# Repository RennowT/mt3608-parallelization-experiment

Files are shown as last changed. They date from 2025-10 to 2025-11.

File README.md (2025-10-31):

# MT3608 Paralelization Experiment

## Overview
This project aims to **develop and validate** a DC-DC boost module composed of **three MT3608 converters in parallel**, designed to **step up voltage to 5 V** with a **target output current of up to 6 A**.

The goal is to evaluate whether multiple MT3608 converters can operate reliably in parallel while maintaining voltage stability, current sharing, and thermal safety.

---

## Objectives
- Design a parallel configuration using **three MT3608 step-up converters**.
- Achieve an **output voltage of 5 V** and up to **6 A total output current**.
- Evaluate **load balancing** and **thermal performance** between converters.
- Analyze the **limitations and failure modes** of MT3608 parallelization.

---

## Current Status
> The project is in an experimental stage.  
> There is **no current validation** that the configuration can achieve the specified current or stability requirements.

Prototype testing and measurement phases are ongoing. Future updates will include:
- Schematics and PCB layout
- Test data (efficiency, ripple, current sharing)
- Thermal analysis

---

## Technical Information
- **IC:** MT3608 (AEROSEMI)
- **Input voltage:** 2 V – 5 V
- **Target output:** 5 V / 6 A (shared)
- **Switching frequency:** 1.2 MHz
- **Topology:** Parallel step-up (boost) converters
- **Package:** SOT-23-6L

---

## License
This project is licensed under the  
**Creative Commons Attribution-NonCommercial-ShareAlike 4.0 International (CC BY-NC-SA 4.0)**.

See the [LICENSE](./LICENSE) file for details.

---

## Author
**Matheus Renó Torres**  
Hardware Research & Development  
2025

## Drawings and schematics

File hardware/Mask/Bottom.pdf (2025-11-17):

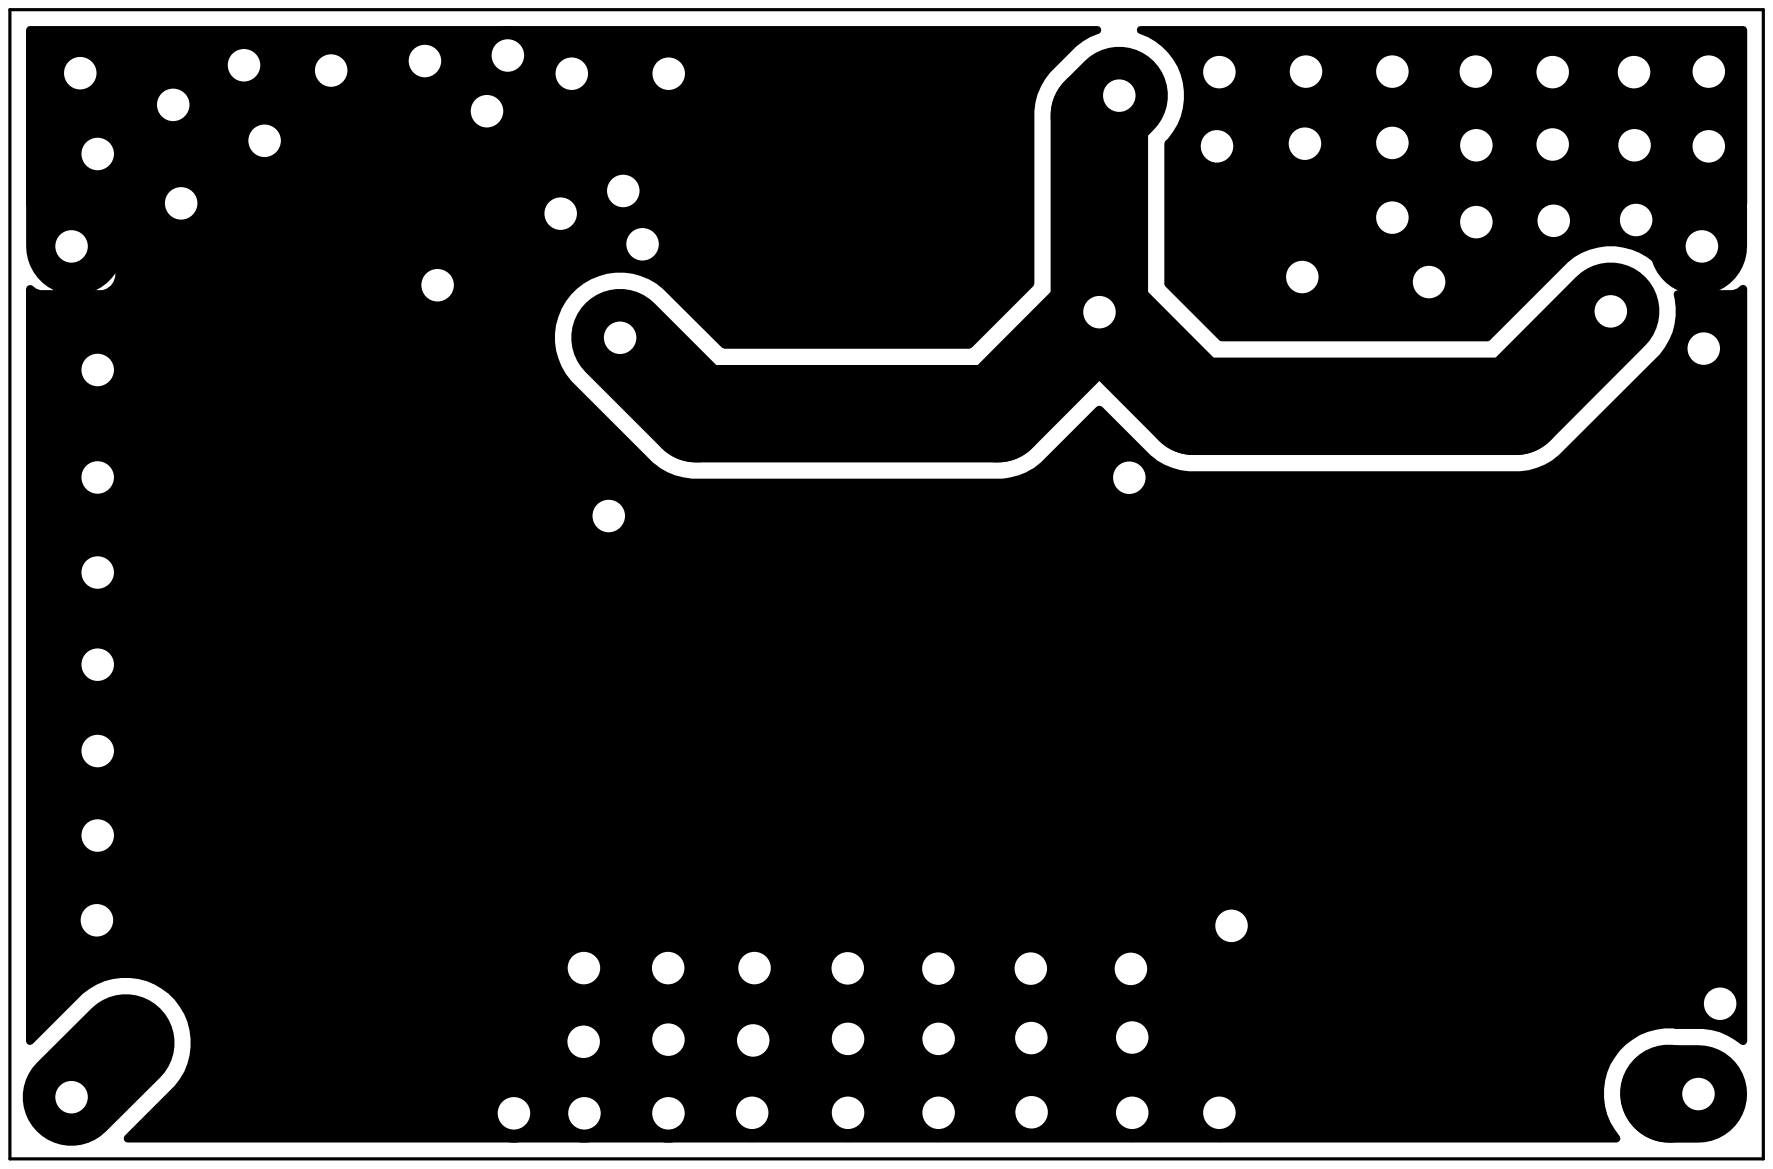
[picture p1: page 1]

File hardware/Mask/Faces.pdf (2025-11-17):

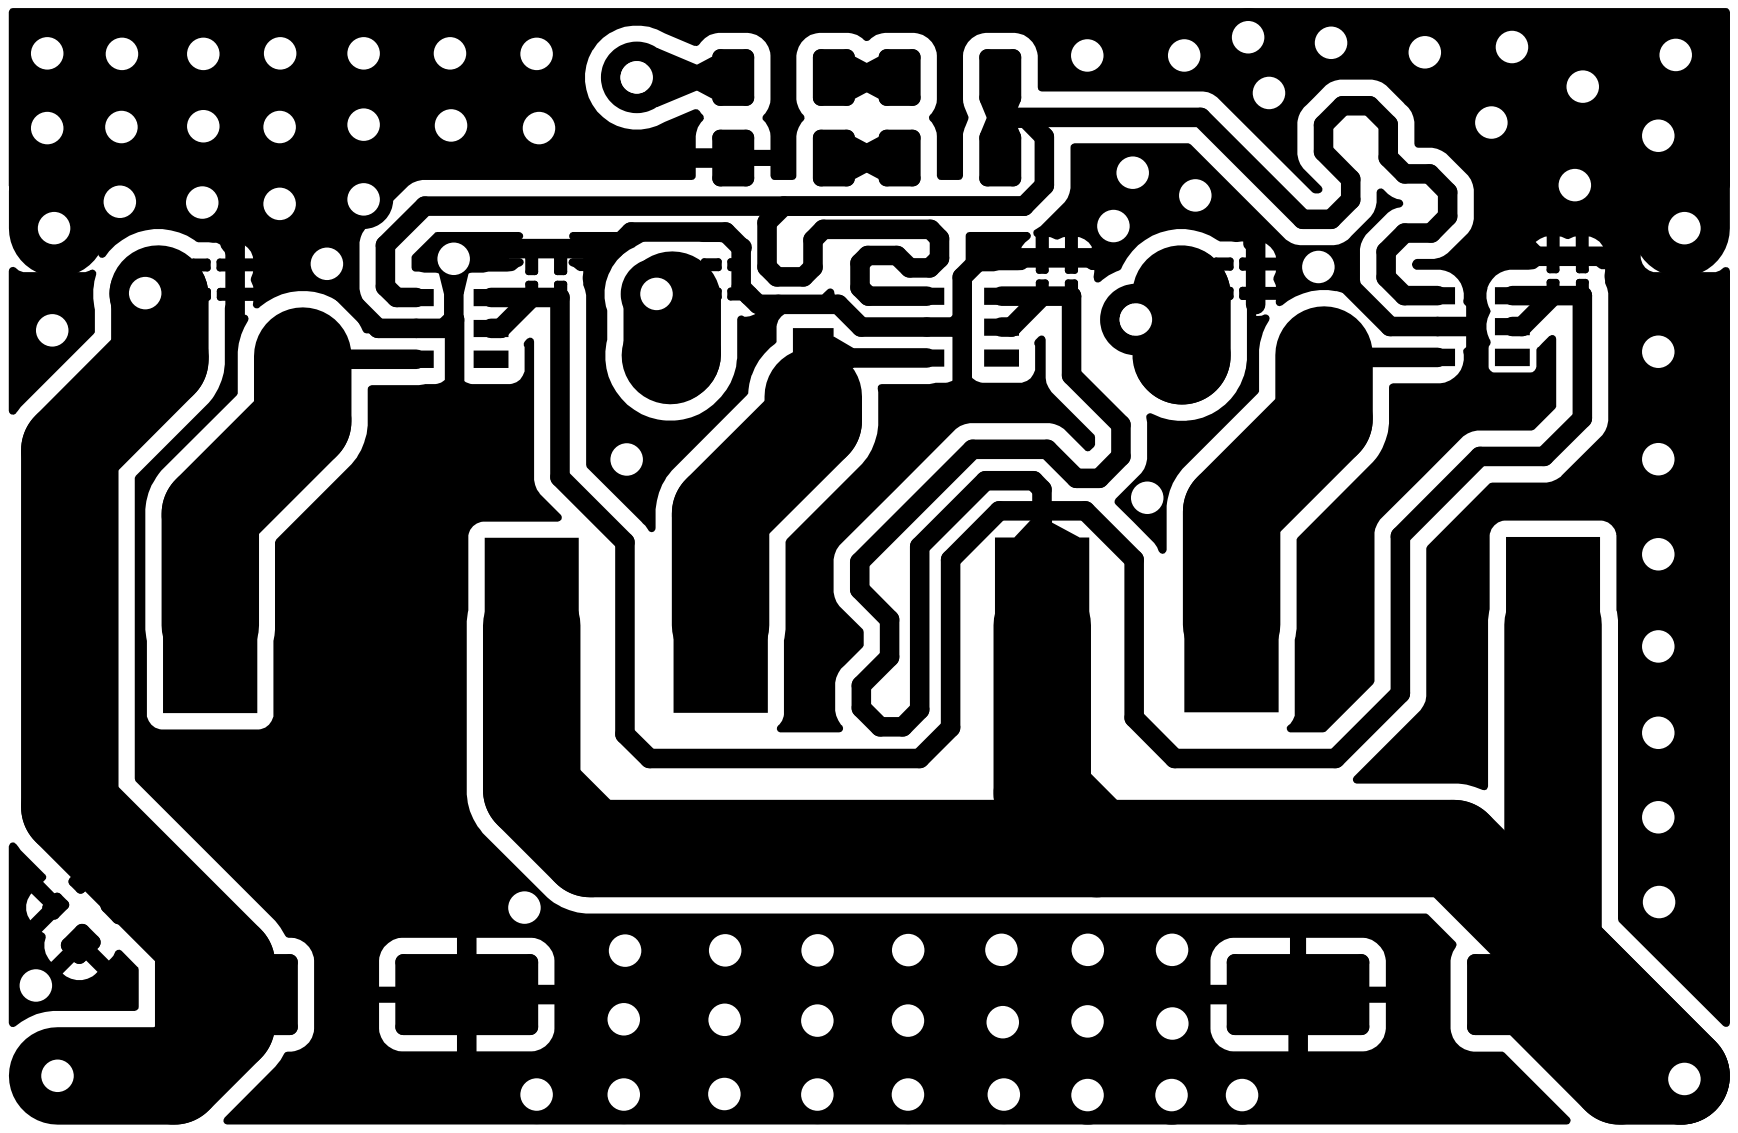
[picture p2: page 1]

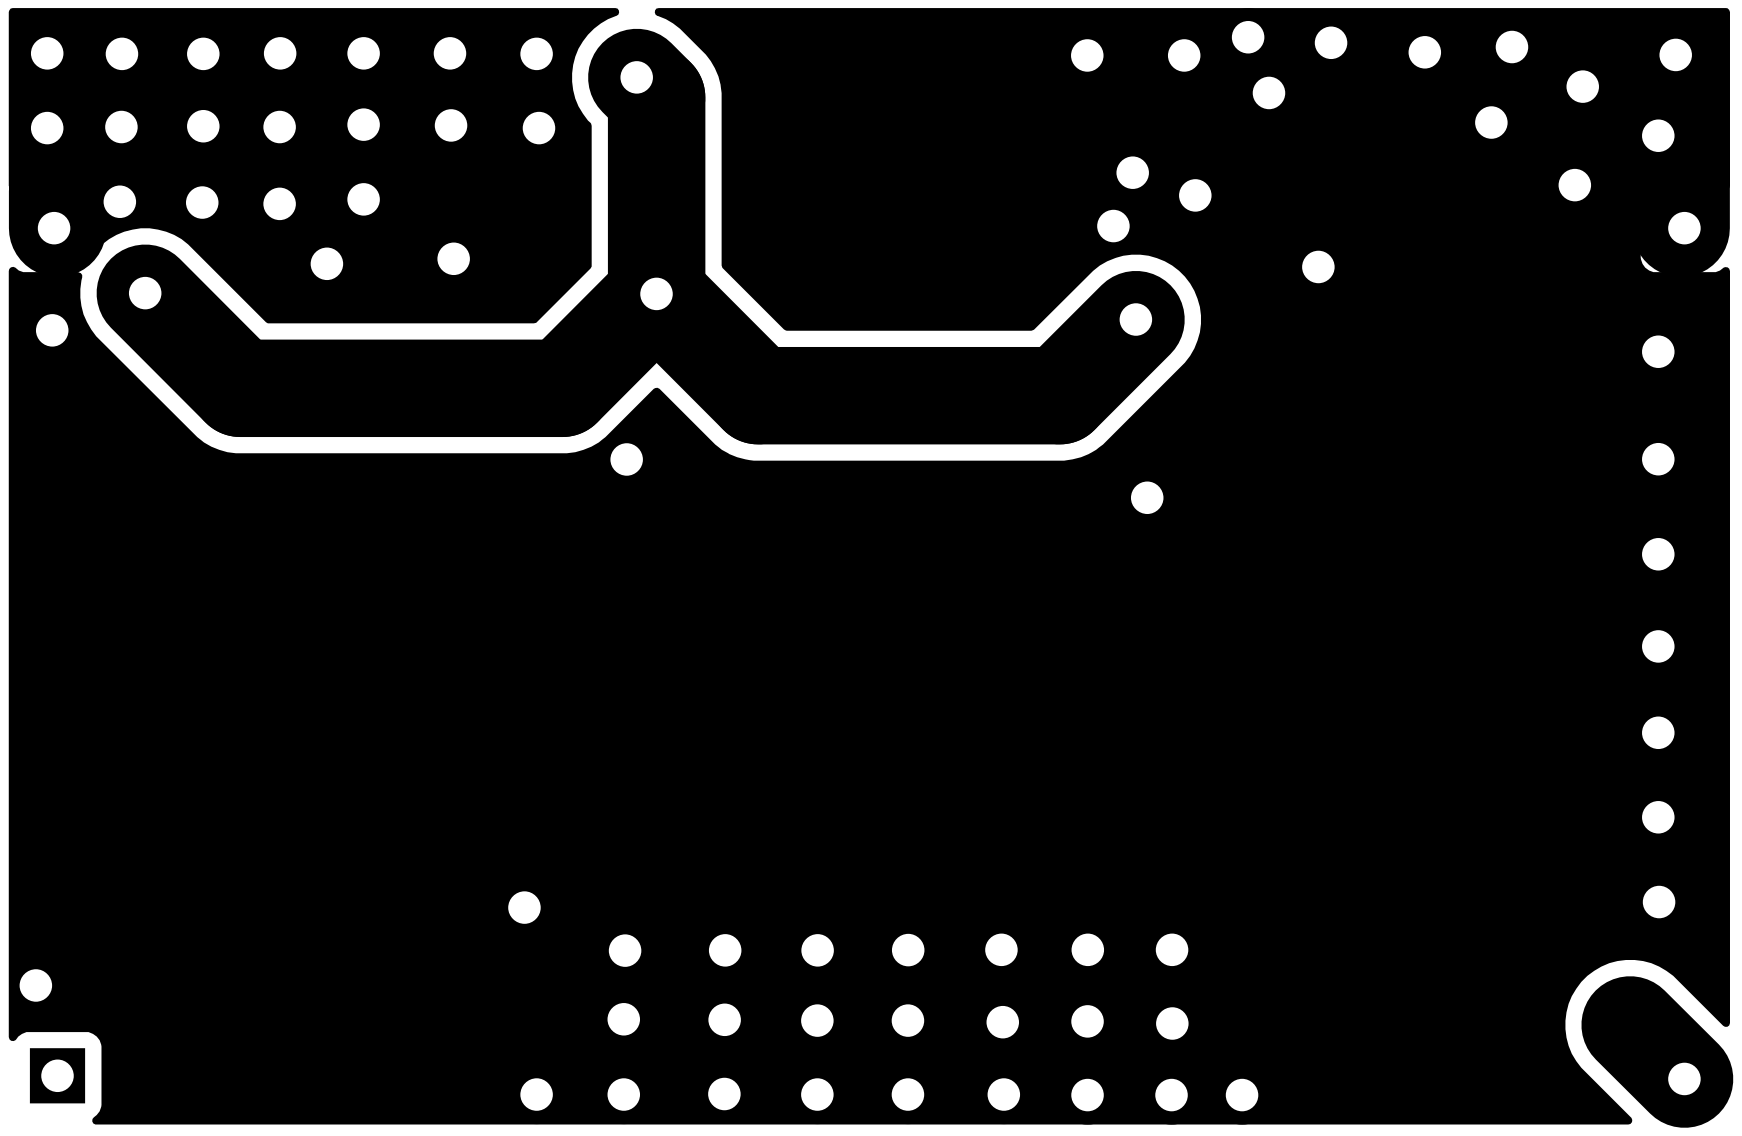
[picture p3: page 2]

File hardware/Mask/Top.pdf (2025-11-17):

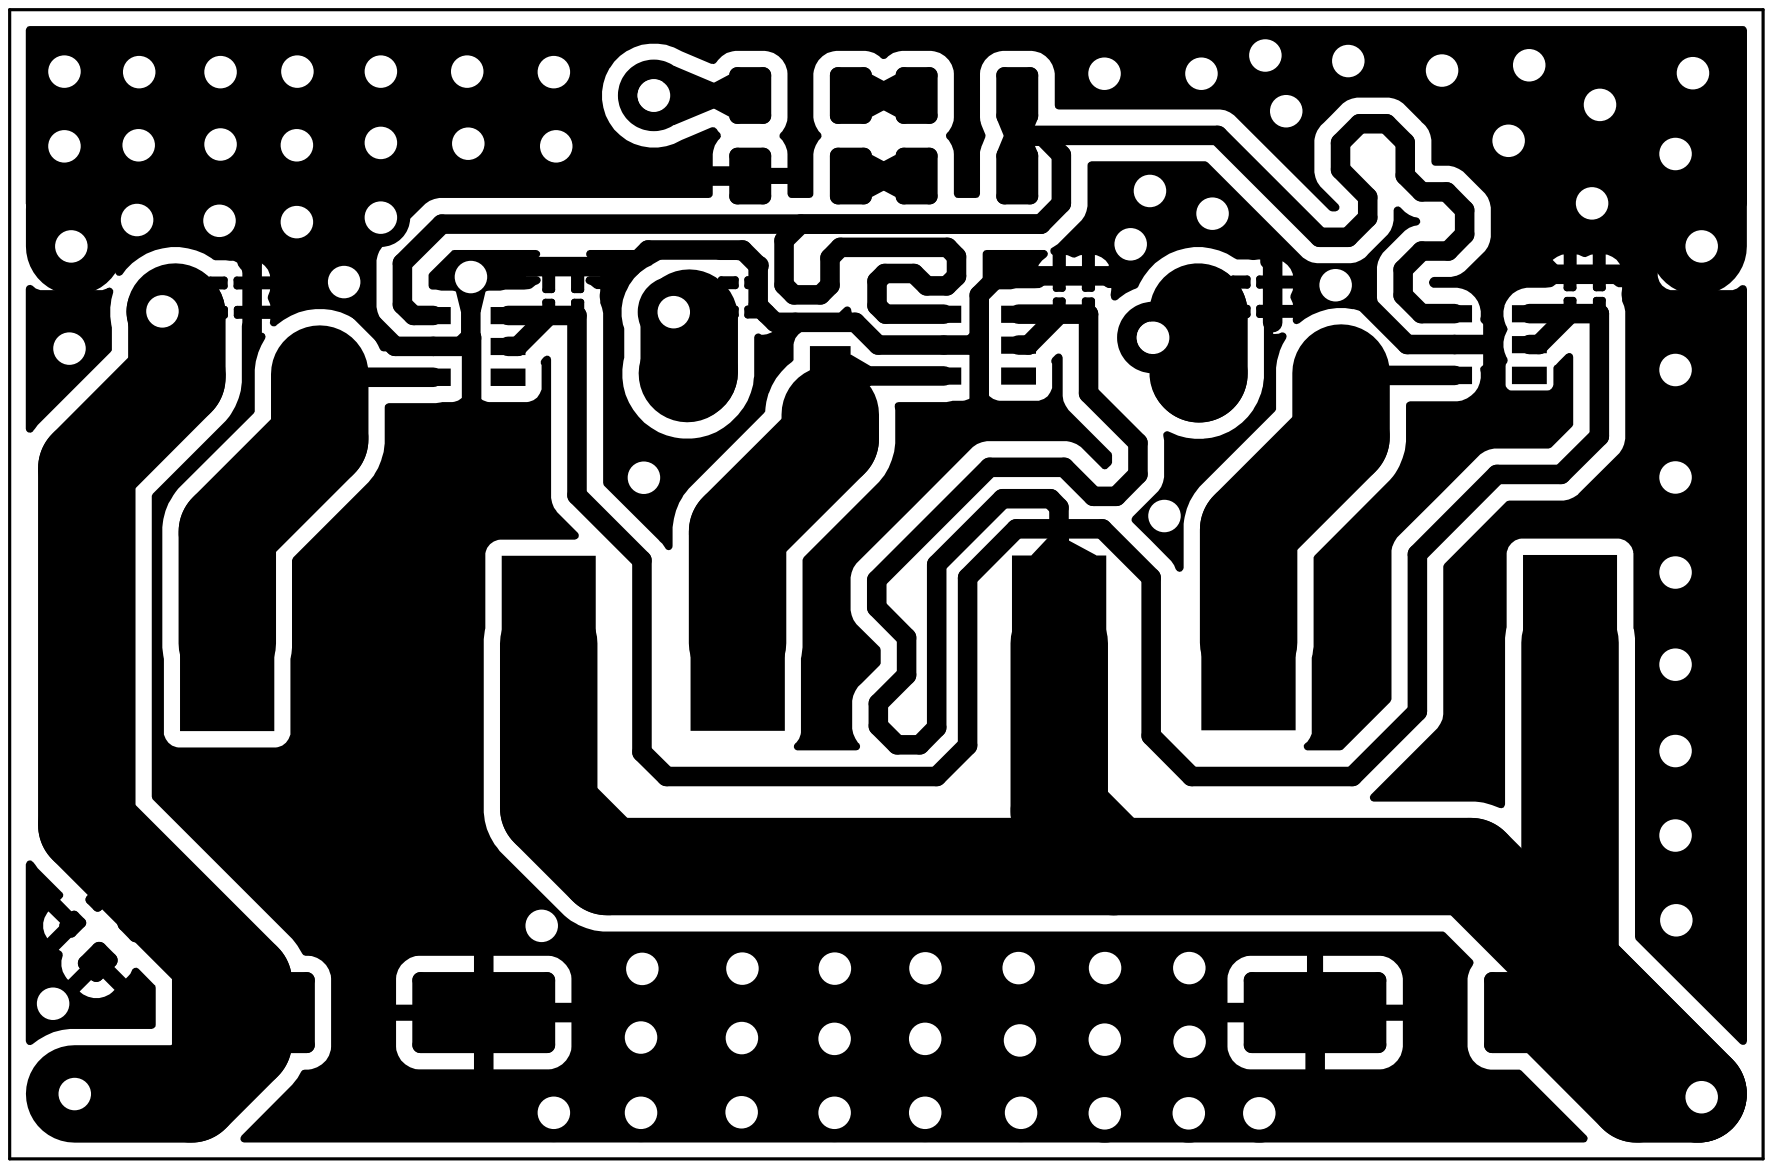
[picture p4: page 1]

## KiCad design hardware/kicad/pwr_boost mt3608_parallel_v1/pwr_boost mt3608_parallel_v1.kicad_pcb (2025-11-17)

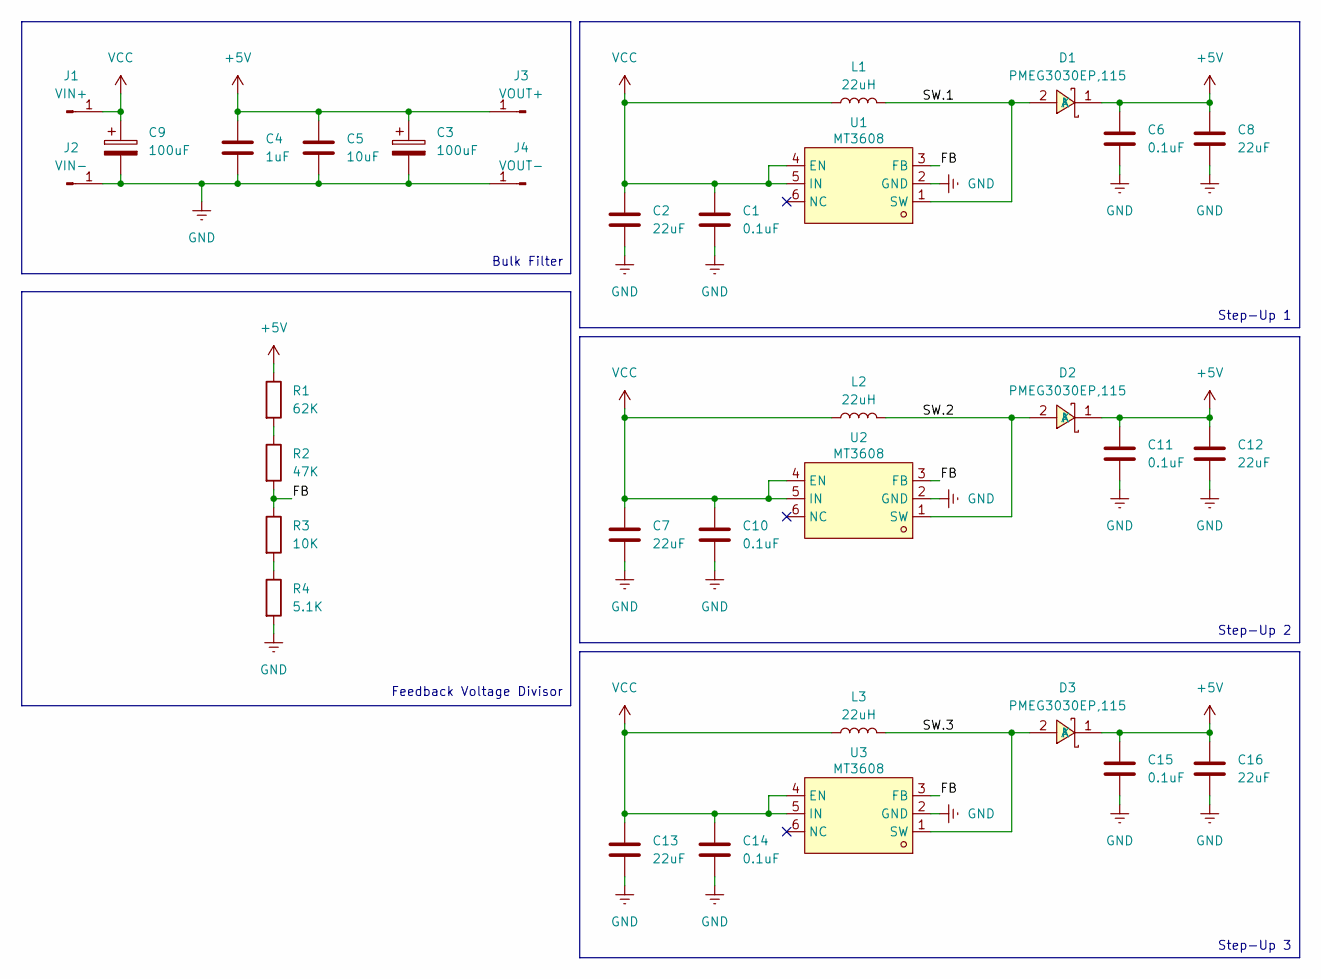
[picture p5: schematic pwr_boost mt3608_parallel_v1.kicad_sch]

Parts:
C1, C6, C10, C11, C14, C15: 0.1uF; C_0201_0603Metric_Pad0.64x0.40mm_HandSolder
C2, C7, C8, C12, C13, C16: 22uF; C_0201_0603Metric_Pad0.64x0.40mm_HandSolder
C3, C9: 100uF; CP_Elec_8x10.5
C4: 1uF; C_0402_1005Metric_Pad0.74x0.62mm_HandSolder
C5: 10uF; C_0603_1608Metric_Pad1.08x0.95mm_HandSolder
D1, D2, D3: PMEG3030EP,115; SOD-128_L3.7-W2.5-LS4.7-RD; LCSC Part C255587
J1: VIN+
J2: VIN-
J3: VOUT+
J4: VOUT-
L1, L2, L3: 22uH; L_12x12mm_H8mm
R1: 62K; R_1206_3216Metric_Pad1.30x1.75mm_HandSolder
R2: 47K; R_1206_3216Metric_Pad1.30x1.75mm_HandSolder
R3: 10K; R_1206_3216Metric_Pad1.30x1.75mm_HandSolder
R4: 5.1K; R_1206_3216Metric_Pad1.30x1.75mm_HandSolder
U1, U2, U3: MT3608; SOT-23-6_L2.9-W1.6-P0.95-LS2.8-BL; LCSC Part C84817

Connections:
+5V: C3.1, C4.1, C5.1, C6.1, C8.1, C11.1, C12.1, C15.1, C16.1, D1.1 (K), D2.1 (K), D3.1 (K), J3.1, R1.1
/FB: R2.2, R3.1, U1.3 (FB), U2.3 (FB), U3.3 (FB)
/SW.1: D1.2 (A), L1.2, U1.1 (SW)
/SW.2: D2.2 (A), L2.2, U2.1 (SW)
/SW.3: D3.2 (A), L3.2, U3.1 (SW)
GND: C1.2, C2.2, C3.2, C4.2, C5.2, C6.2, C7.2, C8.2, C9.2, C10.2, C11.2, C12.2, C13.2, C14.2, C15.2, C16.2, J2.1, J4.1, R4.2, U1.2 (GND), U2.2 (GND), U3.2 (GND)
unnamed: R1.2, R2.1
unnamed: R3.2, R4.1
VCC: C1.1, C2.1, C7.1, C9.1, C10.1, C13.1, C14.1, J1.1, L1.1, L2.1, L3.1, U1.4 (EN), U1.5 (IN), U2.4 (EN), U2.5 (IN), U3.4 (EN), U3.5 (IN)

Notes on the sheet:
Step-Up 3
Bulk Filter
Step-Up 2
Feedback Voltage Divisor
Step-Up 1

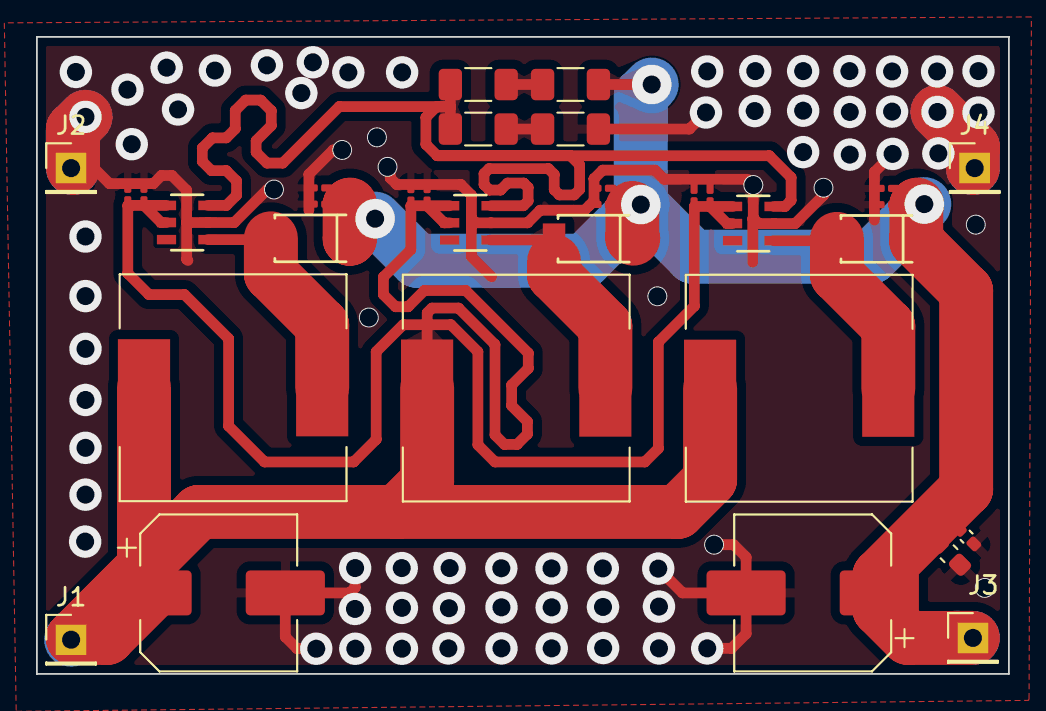
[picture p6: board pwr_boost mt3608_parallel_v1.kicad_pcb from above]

Board: 2 copper layers, 54.0 x 35.4 mm, 33 parts (0 on the bottom side), 9 nets.

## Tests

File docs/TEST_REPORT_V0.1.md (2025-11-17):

# **Version 0.1 — Test Report and Analysis**

## **1. Objective**

Evaluate the behavior of the parallel MT3608 boost converter architecture in an unloaded condition and identify whether all regulators operate simultaneously or if one device dominates the regulation loop.

---

## **2. Test Setup**

* **Input voltage:** 3.7 V
* **Output load:** No load (open circuit)
* **Expected output:** ~5 V
* **Measurement tools:**

  * Oscilloscope (probe on SW pin of each MT3608)
* **Configuration:**

  * Three MT3608 units connected in parallel
  * Shared FB node and identical resistor network
  * Shared output capacitor bank

---

## **3. Test Procedures and Observations**

### **3.1 Initial Power-Up**

* A voltage of **3.7 V** was applied to the input of the system.
* With no load, the output voltage measured **4.92 V**.

### **3.2 Oscilloscope Analysis (SW Pin)**

* The oscilloscope probe was placed on the **SW pin of each MT3608**.
* **Only one IC** showed the normal switching waveform expected from a functioning MT3608.
* The other two devices remained inactive (standby), indicating that only a **single MT3608 was regulating the output**, while the others were not contributing.

### **3.3 Feedback Trace Verification**

* The MT3608 ICs were swapped in their positions to verify whether a PCB feedback-trace issue was preventing regulation.
* After swapping, **the same IC continued to regulate**, regardless of its physical position.
* This eliminates the possibility of a feedback routing or soldering issue on the PCB.

### **3.4 Removal of the Regulating IC**

* The functioning IC was removed from the circuit to observe the behavior of the remaining two devices.
* After removal:

  * A different MT3608 began regulating normally.
  * The third MT3608 continued in standby, unchanged.
  * The new output voltage became **4.83 V**.

---

## **4. Interpretation**

The behavior strongly suggests **mismatch in the internal feedback reference (FB offset)** between individual MT3608 units.
Even within the same manufacturing lot, boost converters can have small variations in the internal 0.6 V reference used for regulation.

Because of this:

* The MT3608 that naturally regulates to the **highest output voltage** becomes the dominant controller.
* It maintains VOUT on its own.
* The other ICs detect that the output voltage is already above their regulation threshold and therefore enter a **standby / PFM state**, never turning on.
* This prevents proper current sharing and makes true parallel operation impossible under the current architecture.

---

## **5. Conclusion**

* The prototype assumed that all MT3608 devices would have identical regulation points; however, real-world variations in **feedback reference voltage** cause each IC to regulate at slightly different output voltages.
* **Only the MT3608 with the highest internal reference (highest regulated VOUT)** becomes active, while the others remain idle.
* This confirms that the current parallel architecture is **not viable** for ensuring simultaneous operation of multiple MT3608 regulators.
* A new design approach is required — one that:

  * Does **not** rely on identical reference voltages,
  * Provides **true current sharing**,
  * Or uses a **single master regulator** followed by distribution elements.

---

## **6. Recommended Next Steps**

To enable proper **parallel operation of multiple MT3608 regulators**, the design must account for the natural variation in the internal 0.6 V feedback reference of each device. Since each MT3608 regulates to a slightly different voltage, only the unit with the highest reference becomes active while the others remain in standby.
A new approach must ensure that all regulators can share current simultaneously.

Recommended next steps:

* Implement a **current-sharing method** between the MT3608 outputs to prevent one IC from dominating the regulation loop.
* Add small **ballast resistors** on each MT3608 output to equalize voltage differences and encourage parallel contribution.
* Isolate each feedback network in a way that minimizes interaction while still maintaining a common output target.
* Evaluate the effect of slightly adjusting the resistor divider of each MT3608 to compensate for reference mismatch.
* Test dynamic behavior under load to understand how the converters transition between PWM and PFM modes when operating together.
* Characterize the feedback reference variation of each MT3608 to define equalization strategies.

This approach retains the goal of **making the MT3608 chips operate in parallel**, avoiding standby dominance and ensuring stable current sharing.

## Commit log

2025-10-31 Revise README with project details and structure
    Updated project title and added detailed sections on objectives, current status, technical information, license, and author.
2025-11-17 feat: hardware design
    [pwr_boost mt3608_parallel_v1.kicad_pcb, pwr_boost mt3608_parallel_v1.kicad_sch]
